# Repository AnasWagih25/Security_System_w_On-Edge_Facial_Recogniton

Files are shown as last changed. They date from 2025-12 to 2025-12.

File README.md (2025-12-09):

# Smart Facial Recognition Security System

This project is a **smart security system** using an **ESP32-CAM**, **Raspberry Pi Pico W**, and a **240x135 Adafruit color TFT**, with **facial recognition**, motion detection, and optional manual keypad entry. It is designed to allow known users immediate access and provide temporary keypad-based access for unknown users while saving power.

---

## Overview

The system performs **facial recognition** via the ESP32-CAM and communicates the results to the Pico W:

- **Known users**: immediate entry, TFT shows the user's name.
- **Unknown users**: after 3 consecutive unknown detections in a short interval, the system prompts for a **manual password** on a 4x4 keypad. Users get **two attempts**.
  - **Correct password** → Access granted.
  - **Failed attempts** → Access denied.
- **Power-saving**: The ESP32-CAM stays in **sleep mode** by default to reduce heat and power consumption. It only activates when **motion is detected**.
- **Motion detection**: The system uses an **EN18 PIR sensor (Passive Infrared Sensor)** to detect nearby presence:
  - Motion detected → camera activates, TFT flash turns on.
  - No motion for 5 seconds after a user leaves → system shuts down.

The TFT shows **entry status** and the detected person (`Anas` or `Marawan` by default). These names are **pre-coded in the ESP32-CAM** and can be updated when enrolling new users.

---

## System Components

1. **ESP32-CAM**
   - Performs **facial recognition**.
   - Sends detected user information to the Pico W via **UART**.
   - Pre-coded IDs correspond to user names; customizable for future users.

2. **Raspberry Pi Pico W**
   - Handles **TFT display**, **motion logic**, and **password entry**.
   - Activates or deactivates system based on motion signals from the EN18 PIR sensor.
   - Manages **manual keypad input** for unknown users.

3. **EN18 PIR Sensor (Passive Infrared Sensor)**
   - Detects motion in front of the system.
   - Triggers ESP32-CAM activation and TFT flash for visibility.

4. **240x135 Adafruit Color TFT**
   - Displays system **status** and **detected user**.
   - Shows **password prompts** and access messages.

5. **4x4 Keypad**
   - Allows manual entry of a password when unknown users are detected.

6. **GSM Module** *(for future features)*
   - Can notify the owner in case of security events (not implemented yet).

## Project Structure
.
├── Code/
│ ├── PicoW_Code/ # Raspberry Pi Pico W scripts
│ └── ESP32_CAM/ # Modified CameraWebServer code + HTML modification script
├── Enclosure_Files/ # 3D enclosure IPT files
├── Snaps/
│ ├── en1.png # Snapshots of 3D enclosure
│ └── En2.png
├── Security_System_Schematic.pdf # Complete wiring schematic
├── LICENSE
└── README.md

---

## Schematic & Enclosure Snapshots

**Wiring Schematic:**  
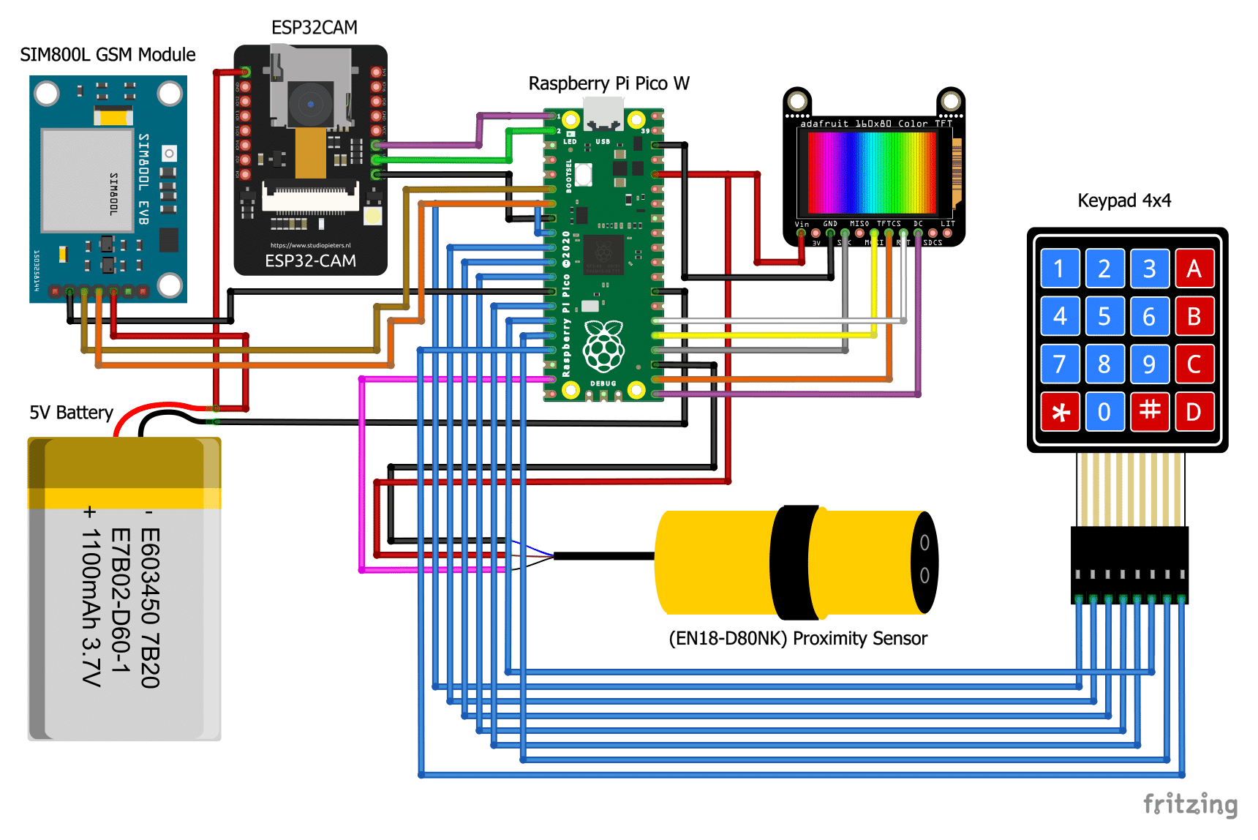
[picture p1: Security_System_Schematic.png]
Schematic
  

**3D Enclosure Snapshots:**

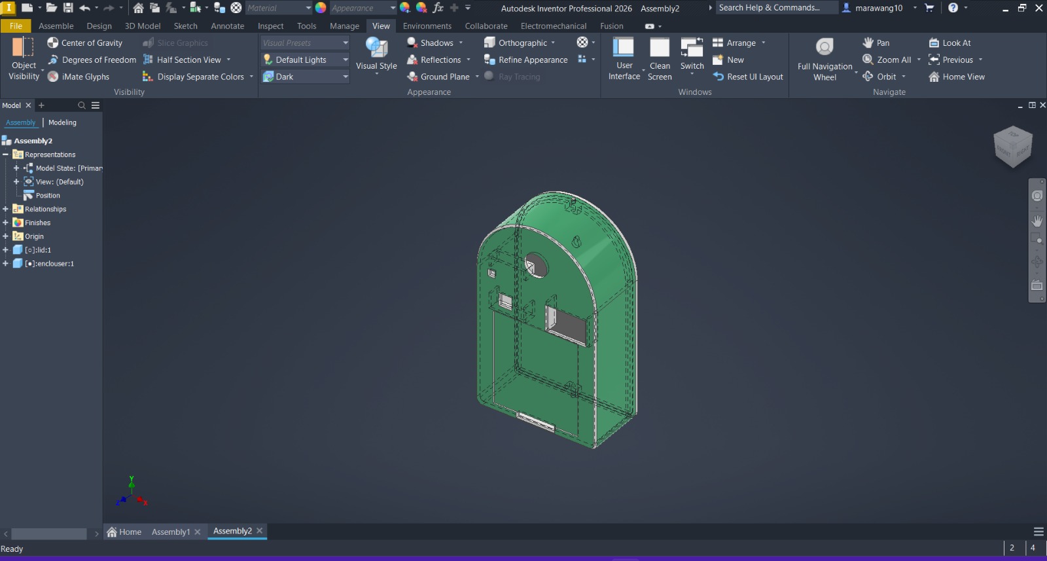
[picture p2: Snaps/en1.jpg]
Enclosure Front
  
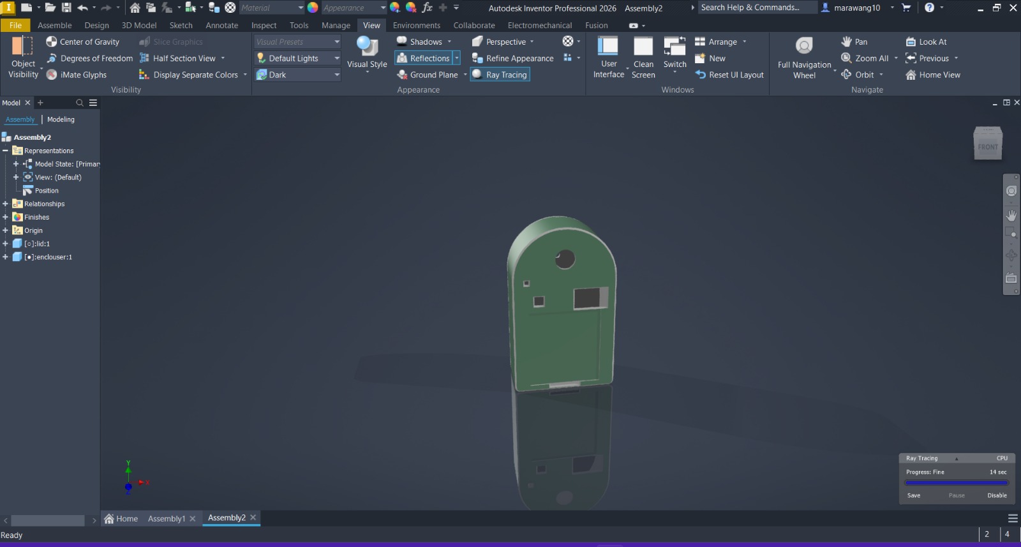
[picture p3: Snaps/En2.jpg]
Enclosure Side


---

## How It Works

1. **Idle / Sleep Mode**
   - ESP32-CAM remains in sleep mode to save power.
   - TFT is on standby.

2. **Motion Detected**
   - EN18 PIR sensor detects motion.
   - TFT flash turns on, camera wakes from sleep.
   - ESP32-CAM captures and processes face images.

3. **Face Detection**
   - Known user → TFT displays name and entry is granted immediately.
   - Unknown user → Counter increments; after 3 consecutive detections, keypad entry is required.

4. **Password Entry**
   - User has **two attempts** to enter the correct passcode.
   - Success → TFT shows **Access Granted**.
   - Failure → TFT shows **Access Denied**.

5. **System Shutdown**
   - After the user leaves or interaction ends, the system waits **5 seconds** of no motion before sending a sleep signal to ESP32-CAM and returning to idle mode.

---

## Setup Instructions

1. **ESP32-CAM**
   - Flash the modified CameraWebServer example located in `Code/ESP32_CAM/`.
   - Use `modify_html.py` to customize the web interface.
   - Connect UART to Pico W (TX/RX) for communication.

2. **Raspberry Pi Pico W**
   - Connect the **TFT display**, **EN18 PIR sensor**, and **4x4 keypad** as per schematic.
   - Flash the Pico W code located in `Code/PicoW_Code/`.
   - Ensure UART pins match ESP32-CAM connections.

3. **3D Enclosure**
   - Use IPT files in `Enclosure_Files/` for reference or fabrication.
   - Snapshots are available in `Snaps/` (`en1.png` and `En2.png`) for visual guidance.

4. **Optional GSM Module**
   - Wiring included in the schematic; can be used later to alert the owner.

---

## Notes

- Pre-coded user IDs in ESP32-CAM must be updated when enrolling new faces.
- Motion sensor logic is **active-low** (triggers when sensor reads LOW).
- System balances **security** and **power efficiency**, keeping the camera in sleep mode until needed.

---

## License

Open-source for educational and personal use.

---

## Author

**Anas Wagih & Marawan Ghazy**

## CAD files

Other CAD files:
Enclosure_Files/Assembly.iam
Enclosure_Files/Enclosure.ipt
Enclosure_Files/Lid.ipt

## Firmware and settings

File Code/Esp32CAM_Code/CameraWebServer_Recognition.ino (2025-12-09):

#include "esp_camera.h"
#include <WiFi.h>

//
// WARNING!!! Make sure that you have either selected ESP32 Wrover Module,
//            or another board which has PSRAM enabled
//

// Select camera model
//#define CAMERA_MODEL_WROVER_KIT
//#define CAMERA_MODEL_ESP_EYE
//#define CAMERA_MODEL_M5STACK_PSRAM
//#define CAMERA_MODEL_M5STACK_WIDE
#define CAMERA_MODEL_AI_THINKER

#include "camera_pins.h"

// Hardware UART for communication with Raspberry Pi Pico
// GPIO 1 = TX (ESP32 sends to Pico GP0/RX)
// GPIO 2 = RX (ESP32 receives from Pico GP1/TX)
#define UART_TX_PIN 1
#define UART_RX_PIN 3
HardwareSerial SerialPico(1);  // Use UART1 for Pico communication

const char* ssid = "Your Network SSID"; //Change to the network name
const char* password = "Password"; //Network Password

void startCameraServer();
void enableFaceDetection();
void disableFaceDetection();
void enableFaceRecognition();
void disableFaceRecognition();
void activateStream();
void sleepStream();

void setup() {
  Serial.begin(115200);
  Serial.setDebugOutput(true);
  Serial.println();

  camera_config_t config;
  config.ledc_channel = LEDC_CHANNEL_0;
  config.ledc_timer = LEDC_TIMER_0;
  config.pin_d0 = Y2_GPIO_NUM;
  config.pin_d1 = Y3_GPIO_NUM;
  config.pin_d2 = Y4_GPIO_NUM;
  config.pin_d3 = Y5_GPIO_NUM;
  config.pin_d4 = Y6_GPIO_NUM;
  config.pin_d5 = Y7_GPIO_NUM;
  config.pin_d6 = Y8_GPIO_NUM;
  config.pin_d7 = Y9_GPIO_NUM;
  config.pin_xclk = XCLK_GPIO_NUM;
  config.pin_pclk = PCLK_GPIO_NUM;
  config.pin_vsync = VSYNC_GPIO_NUM;
  config.pin_href = HREF_GPIO_NUM;
  config.pin_sscb_sda = SIOD_GPIO_NUM;
  config.pin_sscb_scl = SIOC_GPIO_NUM;
  config.pin_pwdn = PWDN_GPIO_NUM;
  config.pin_reset = RESET_GPIO_NUM;
  config.xclk_freq_hz = 20000000;
  config.pixel_format = PIXFORMAT_JPEG;
  //init with high specs to pre-allocate larger buffers
  if(psramFound()){
    config.frame_size = FRAMESIZE_UXGA;
    config.jpeg_quality = 10;
    config.fb_count = 2;
  } else {
    config.frame_size = FRAMESIZE_SVGA;
    config.jpeg_quality = 12;
    config.fb_count = 1;
  }

#if defined(CAMERA_MODEL_ESP_EYE)
  pinMode(13, INPUT_PULLUP);
  pinMode(14, INPUT_PULLUP);
#endif

  // camera init
  esp_err_t err = esp_camera_init(&config);
  if (err != ESP_OK) {
    Serial.printf("Camera init failed with error 0x%x", err);
    return;
  }

  sensor_t * s = esp_camera_sensor_get();
  //initial sensors are flipped vertically and colors are a bit saturated
  if (s->id.PID == OV3660_PID) {
    s->set_vflip(s, 1);//flip it back
    s->set_brightness(s, 1);//up the blightness just a bit
    s->set_saturation(s, -2);//lower the saturation
  }
  //drop down frame size for higher initial frame rate
  s->set_framesize(s, FRAMESIZE_QVGA);

#if defined(CAMERA_MODEL_M5STACK_WIDE)
  s->set_vflip(s, 1);
  s->set_hmirror(s, 1);
#endif

  // Initialize GPIO 4 for LED flash control
  pinMode(4, OUTPUT);
  digitalWrite(4, LOW);  // Start with LED off

  // Initialize hardware UART for Pico communication
  SerialPico.begin(115200, SERIAL_8N1, UART_RX_PIN, UART_TX_PIN);
  Serial.println("Hardware UART initialized for Pico communication (RX=GPIO2, TX=GPIO1)");

  WiFi.begin(ssid, password);

  while (WiFi.status() != WL_CONNECTED) {
    delay(500);
    Serial.print(".");
  }
  Serial.println("");
  Serial.println("WiFi connected");

  startCameraServer();

  Serial.print("Camera Ready! Use 'http://");
  Serial.print(WiFi.localIP());
  Serial.println("' to connect");
}

void loop() {
  // Check for UART messages from Pico (hardware UART)
  if (SerialPico.available() > 0) {
    char received = SerialPico.read();  // Read single character
    
    Serial.print("Received from Pico: ");
    Serial.println(received);
    
    if (received == 'M') {  // Motion Detected
      digitalWrite(4, HIGH);  // Turn GPIO 4 HIGH
      Serial.println("LED Flash ON - Motion Detected");
    } else if (received == 'X') {  // Activate
      // Activate stream with face detection and recognition
      activateStream();
    } else if (received == 'S') {  // Sleep
      // Put stream to sleep
      sleepStream();
    }
  }
  
  delay(10);  // Small delay to prevent overwhelming the CPU
}

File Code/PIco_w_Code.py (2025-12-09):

import board 
import busio
import displayio
import terminalio
from digitalio import DigitalInOut, Direction
from adafruit_display_text import label
from fourwire import FourWire
from adafruit_st7789 import ST7789
import time
import keypad  # for matrix keypad

displayio.release_displays()

# ========= DISPLAY SETUP =========
spi = busio.SPI(clock=board.GP18, MOSI=board.GP19)
tft_cs = board.GP17
tft_dc = board.GP16
tft_rst = board.GP20

display_bus = FourWire(spi, command=tft_dc, chip_select=tft_cs, reset=tft_rst)
display = ST7789(display_bus, rotation=270, width=240, height=135, rowstart=40, colstart=53)

# ========= UI =========
splash = displayio.Group()
display.root_group = splash

bg_bitmap = displayio.Bitmap(display.width, display.height, 2)
bg_palette = displayio.Palette(2)
bg_palette[0] = 0x000000  # black
bg_palette[1] = 0x111111  # alternate for flash
bg_tilegrid = displayio.TileGrid(bg_bitmap, pixel_shader=bg_palette)
splash.append(bg_tilegrid)

status_label = label.Label(terminalio.FONT, text="Status: Off", color=0x00FF00)
detect_label = label.Label(terminalio.FONT, text="Detection: Null", color=0x00FF00)
group1 = displayio.Group(scale=2, x=10, y=40)
group2 = displayio.Group(scale=2, x=10, y=80)
group1.append(status_label)
group2.append(detect_label)
splash.append(group1)
splash.append(group2)

motion_bitmap = displayio.Bitmap(display.width, 10, 1)
motion_palette = displayio.Palette(1)
motion_palette[0] = 0x00FF00
motion_tile = displayio.TileGrid(motion_bitmap, pixel_shader=motion_palette, x=0, y=0)
splash.append(motion_tile)
motion_tile.hidden = True

display.refresh()

# ========= SENSOR =========
sensor = DigitalInOut(board.GP21)
sensor.direction = Direction.INPUT
sensor.pull = None  # PIR is inverted, no pull

# ========= UART =========
uart = busio.UART(board.GP0, board.GP1, baudrate=115200, timeout=0.1)

# ========= KEYPAD =========
rows = [board.GP2, board.GP3, board.GP4, board.GP5]
cols = [board.GP6, board.GP7, board.GP8, board.GP9]
key_map = [
    ["1","2","3","A"],
    ["4","5","6","B"],
    ["7","8","9","C"],
    ["*","0","#","D"]
]
flat_keys = [k for row in key_map for k in row]  # flatten for key_number indexing
keypad_matrix = keypad.KeyMatrix(rows, cols, columns_to_anodes=False)

# ========= STATE =========
motion_active = False
sent_sleep = False
last_motion_time = 0
unknown_count = 0
password_mode = False
password_attempts = 0
entered_password = ""
PASSWORD = "220044"
SLEEP_DELAY = 5  # seconds after no motion to send "S"

def set_status_off():
    status_label.text = "Status: Off"
    detect_label.text = "Detection: Null"
    display.refresh()

def set_status_on(name):
    status_label.text = "Status: On"
    detect_label.text = "Detection: " + name
    if name == "Anas":
        status_label.color = 0x1E90FF
        detect_label.color = 0x1E90FF
    elif name == "Marawan":
        status_label.color = 0xFFA500
        detect_label.color = 0xFFA500
    display.refresh()

def show_password_prompt():
    status_label.text = "Enter Password"
    detect_label.text = ""
    display.refresh()

def check_password():
    global entered_password, password_attempts, password_mode
    if entered_password == PASSWORD:
        status_label.text = "Access Granted"
        detect_label.text = ""
        password_mode = False
    else:
        password_attempts += 1
        if password_attempts >= 2:
            status_label.text = "Access Denied"
            detect_label.text = ""
            password_mode = False
        else:
            show_password_prompt()
    entered_password = ""
    display.refresh()

# ========= MAIN LOOP =========
while True:
    now = time.monotonic()

    # ----- MOTION HANDLING (PIR inverted) -----
    if not sensor.value:  # motion detected
        last_motion_time = now
        if not motion_active:
            motion_active = True
            sent_sleep = False
            uart.write(b"M")
            time.sleep(0.05)
            uart.write(b"X")
            motion_tile.hidden = False
        display.refresh()
    else:  # no motion
        motion_tile.hidden = True
        if motion_active and (now - last_motion_time >= SLEEP_DELAY):
            motion_active = False
            if not sent_sleep:
                uart.write(b"S")
                set_status_off()
                sent_sleep = True
        display.refresh()

    # ----- UART FACE DETECTION -----
    data = uart.read(64)
    if data:
        try:
            msg = data.decode('utf-8').strip()
            for c in msg:
                if password_mode:
                    continue  # ignore face detection during password entry
                if c == "A":
                    set_status_on("Anas")
                    unknown_count = 0
                elif c == "M":
                    set_status_on("Marawan")
                    unknown_count = 0
                elif c == "U":
                    unknown_count += 1
                    detect_label.text = "Detection: Unknown"
                    status_label.text = "Status: Off"
                    display.refresh()
                    if unknown_count >= 3:
                        password_mode = True
                        password_attempts = 0
                        entered_password = ""
                        show_password_prompt()
                        unknown_count = 0
        except UnicodeError:
            print("Received non-UTF8 data:", data)

    # ----- KEYPAD PASSWORD ENTRY -----
    if password_mode:
        key_event = keypad_matrix.events.get()
        while key_event:
            if key_event.pressed:
                key = flat_keys[key_event.key_number]
                if key in "0123456789":
                    entered_password += key
                    detect_label.text = "*" * len(entered_password)
                    display.refresh()
                    if len(entered_password) >= len(PASSWORD):
                        check_password()
            key_event = keypad_matrix.events.get()

    time.sleep(0.05)

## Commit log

2025-12-09 Revise README for Smart Facial Recognition System
    Updated project description and added detailed system components, setup instructions, and operational flow.
2025-12-09 Change enclosure snapshot images to JPG format
    Updated image file extensions from PNG to JPG for enclosure snapshots.
2025-12-09 Update schematic link to image format
